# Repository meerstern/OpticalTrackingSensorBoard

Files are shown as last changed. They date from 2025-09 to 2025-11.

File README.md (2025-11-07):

# Optical Tracking Sensor Board

## Feature
  * An optical tracking sensor board using PAT9125EL-TKIT manufactured by PixArt Imaging.  
  * It is possible to detect two-dimensional movement with one sensor.  
  * It can detect object movement at a distance of 1 to 30 mm.
  * No additional lens is required.  
  * Programmable resolution up to 1,275cpi.  
  * It can be easily connected via I2C (Grove compatible connector).  
  * This board is equipped with voltage level conversion, so it can be directly connected to 5V systems such as Arduino Uno.  

## Application
  * Tracking on a Moving Surface  
  * Tracking on the Side of a Rotational Shaft
  
## Note
  * Power/I2C 3.3V-5V  
  * This board is equipped with the PAT9125EL-TKIT, which is an I2C connection type, and does not support SPI connection.

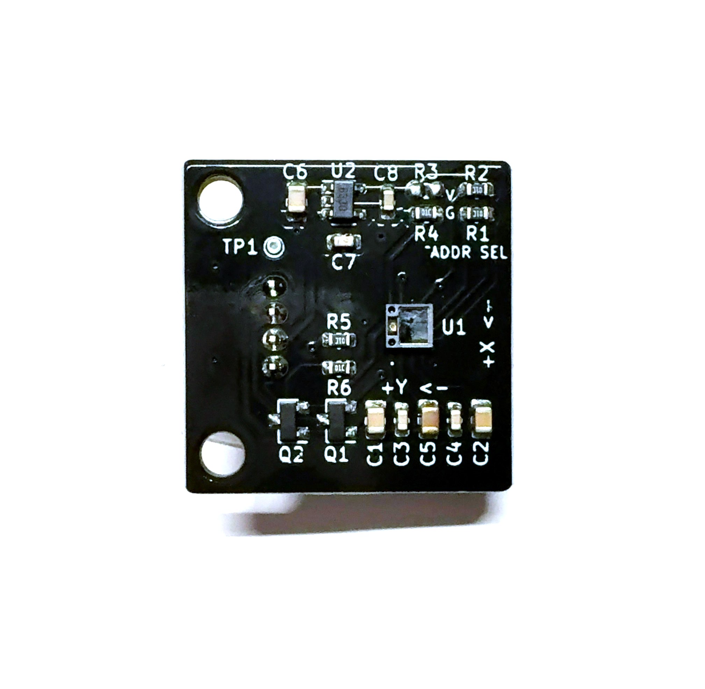
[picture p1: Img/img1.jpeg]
 
   
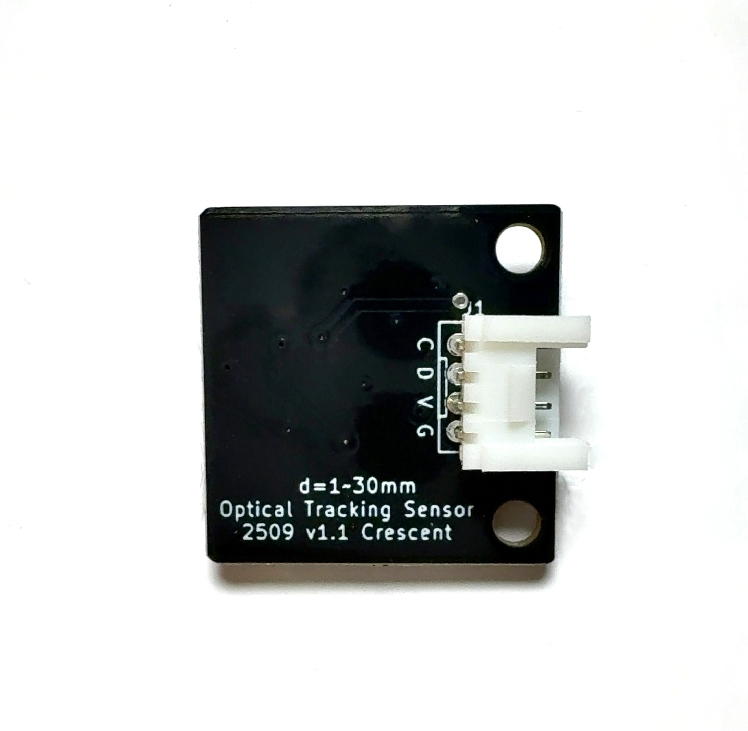
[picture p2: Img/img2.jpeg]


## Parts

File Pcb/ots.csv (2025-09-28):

ID | 参照記号 | パッケージ | 数 | 名称 | Supplier and ref
1 | REF1,REF2 | MountingHole_3.2mm_M3 | 2 | MountingHole_3.2mm_M3
2 | U2 | SOT-23-5 | 1 | LD3985M33R_SOT23
3 | R6,R5,R4,R3,R2,R1 | R_0603_1608Metric | 6 | 10k
4 | Q2,Q1 | SOT-23 | 2 | Q_NMOS_GSD
5 | C8 | C_0603_1608Metric | 1 | 1u
6 | C7 | C_0603_1608Metric | 1 | 10n
7 | C6,C5 | C_0805_2012Metric | 2 | 4.7u
8 | U1 | PAT9125EL | 1 | PAT9125EL
9 | TP1 | TestPoint_THTPad_D1.0mm_Drill0.5mm | 1 | MOTION
10 | J1 | GROVE | 1 | Grove
11 | C4,C3 | C_0603_1608Metric | 2 | 0.1u
12 | C2,C1 | C_0805_2012Metric | 2 | 10u

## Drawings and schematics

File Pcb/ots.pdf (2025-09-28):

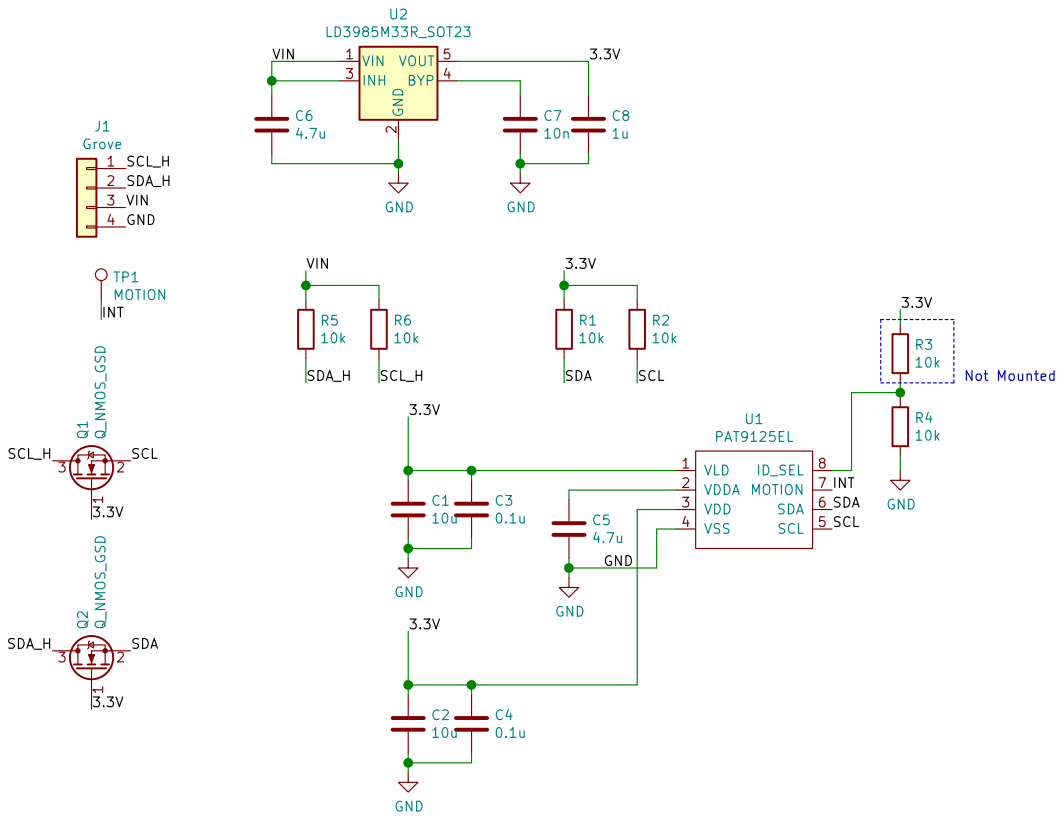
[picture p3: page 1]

Id: 1/1 Title: Optical Tracking Sensor File: ots.sch Sheet: / Crescent

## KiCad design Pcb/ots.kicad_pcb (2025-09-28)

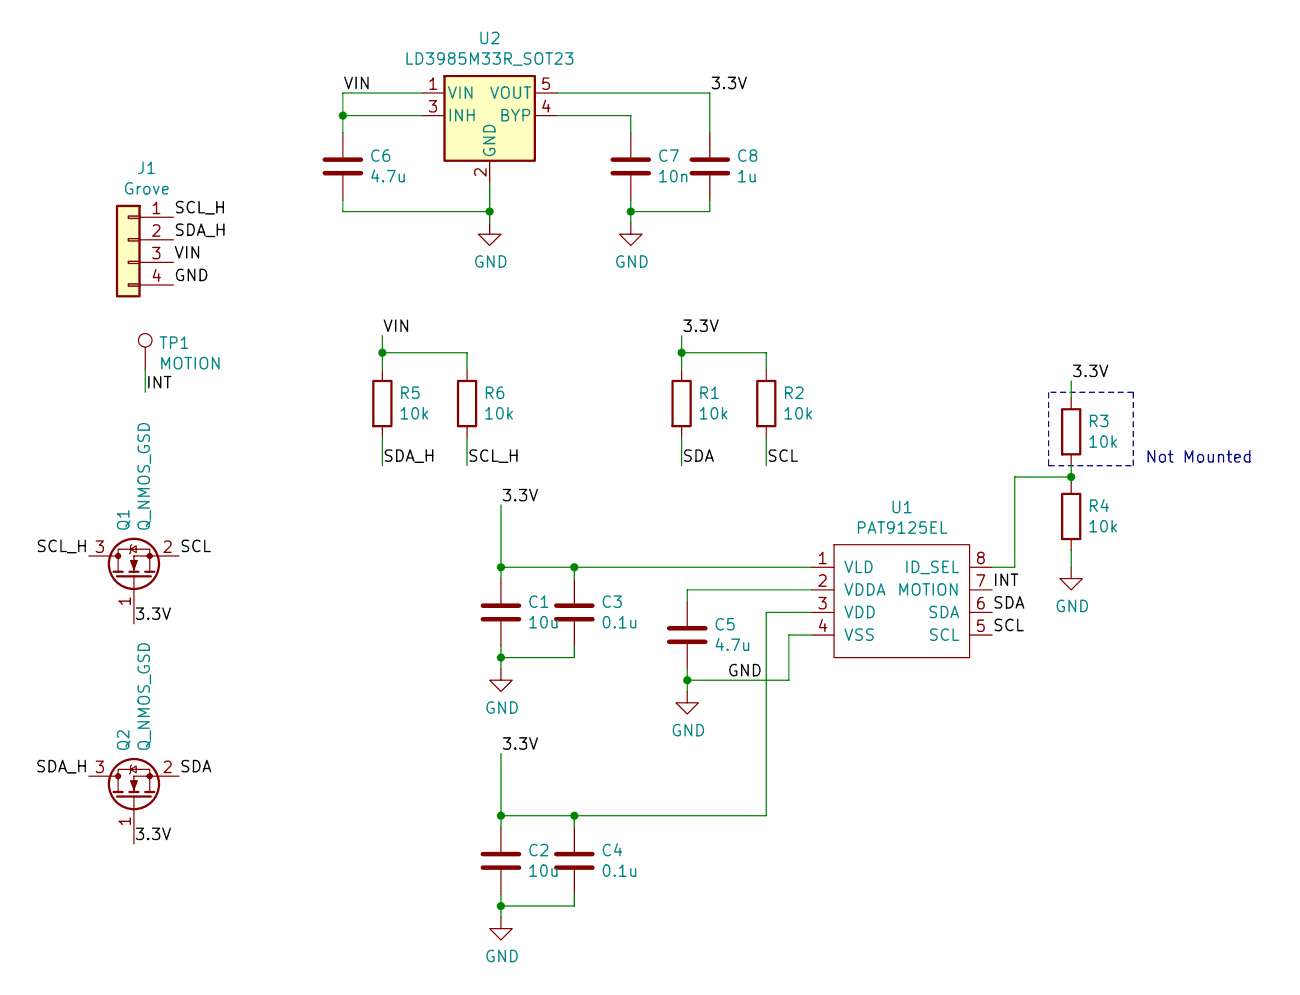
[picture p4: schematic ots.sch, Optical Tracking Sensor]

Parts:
C1, C2: 10u; C_0805_2012Metric
C3, C4: 0.1u; C_0603_1608Metric
C5, C6: 4.7u; C_0805_2012Metric
C7: 10n; C_0603_1608Metric
C8: 1u; C_0603_1608Metric
J1: Grove; GROVE
Q1, Q2: Q_NMOS_GSD; SOT-23
R1, R2, R3, R4, R5, R6: 10k; R_0603_1608Metric
TP1: MOTION; TestPoint_THTPad_D1.0mm_Drill0.5mm
U1: PAT9125EL
U2: LD3985M33R_SOT23; SOT-23-5

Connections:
/3.3V: C1.1, C2.1, C3.1, C4.1, C8.1, Q1.1 (G), Q2.1 (G), R1.1, R2.1, R3.1, U1.1 (VLD), U1.3 (VDD), U2.5 (VOUT)
/INT: TP1.1, U1.7 (MOTION)
/SCL: Q1.2 (S), R2.2, U1.5 (SCL)
/SCL_H: J1.1, Q1.3 (D), R6.2
/SDA: Q2.2 (S), R1.2, U1.6 (SDA)
/SDA_H: J1.2, Q2.3 (D), R5.2
/VIN: C6.1, J1.3, R5.1, R6.1, U2.1 (VIN), U2.3 (INH)
GND: C1.2, C2.2, C3.2, C4.2, C5.2, C6.2, C7.2, C8.2, J1.4, R4.2, U1.4 (VSS), U2.2 (GND)
unnamed: C5.1, U1.2 (VDDA)
unnamed: C7.1, U2.4 (BYP)
unnamed: R3.2, R4.1, U1.8 (ID_SEL)

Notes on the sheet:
Not Mounted

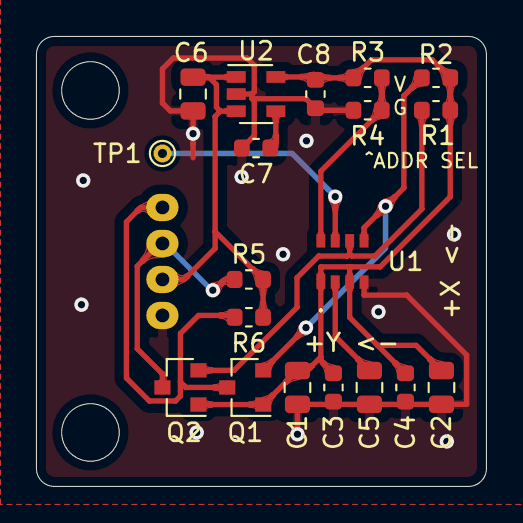
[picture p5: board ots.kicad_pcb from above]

Board: 2 copper layers, 25.0 x 25.0 mm, 22 parts (1 on the bottom side), 11 nets.

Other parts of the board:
REF1, REF2: MountingHole_3.2mm_M3

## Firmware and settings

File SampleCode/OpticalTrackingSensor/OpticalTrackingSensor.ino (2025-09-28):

// PAT9125EL: Miniature Optical Navigation Chip reference code.
// Version: 1.2
// Latest Revision Date: 23 July 2018
// By PixArt Imaging Inc.
// Primary Engineer: Vincent Yeh (PixArt USA)

// Copyright [2018] [Vincent Yeh]
// Licensed under the Apache License, Version 2.0 (the "License"); you may not use this file except in compliance with the License. You may obtain a copy of the License at:
// http://www.apache.org/licenses/LICENSE-2.0

#include <Arduino.h>
#include <Wire.h>

#define WIRE Wire

const uint8_t initialize[][2] = {
    { 0x09, 0x5A },     //Disables write-protect.
    { 0x0D, 0xB5 },     //Sets X-axis resolution (necessary value here will depend on physical design and application).
    { 0x0E, 0xFF },     //Sets Y-axis resolution (necessary value here will depend on physical design and application).
    { 0x19, 0x04 },     //Sets 12-bit X/Y data format.
    //{ 0x4B, 0x04 },     //Needed for when using low-voltage rail (1.7-1.9V): Power saving configuration.
};
#define initialize_size (sizeof(initialize)/sizeof(initialize[0]))

#define I2C_Slave_ID 0x75                           //ONLY WHEN ID PIN IS TIED TO GROUND! ID changes when tied to VDD (0x73) or when left floating (0x79).

int8_t deltaX_low, deltaY_low;                      //Stores the low-bits of movement data.
int16_t deltaX_high, deltaY_high;                   //Stores the high-bits of movement data.
int16_t deltaX, deltaY;                             //Stores the combined value of low and high bits.
int16_t totalX, totalY = 0;                         //Stores the total deltaX and deltaY moved during runtime.

uint8_t readRegister(uint8_t addr)
{
    uint8_t data;
    WIRE.beginTransmission(I2C_Slave_ID);
    WIRE.write(addr);
    WIRE.endTransmission(0);
    WIRE.requestFrom((uint8_t)I2C_Slave_ID,(uint8_t)1);
    data = WIRE.read();
    return(data);
}

void writeRegister(uint8_t addr, uint8_t data)
{
    WIRE.beginTransmission(I2C_Slave_ID);
    WIRE.write(addr);
    WIRE.write(data);
}

void load(const uint8_t array[][2], uint8_t arraySize)
{
    for(uint8_t q = 0; q < arraySize; q++)
    {
        writeRegister(array[q][0], array[q][1]);    //Writes the given array of registers/data.
    }
}

void grabData(void)
{
    deltaX_low = readRegister(0x03);        //Grabs data from the proper registers.
    deltaY_low = readRegister(0x04);
    deltaX_high = (readRegister(0x12)<<4) & 0xF00;      //Grabs data and shifts it to make space to be combined with lower bits.
    deltaY_high = (readRegister(0x12)<<8) & 0xF00;
    
    if(deltaX_high & 0x800)
        deltaX_high |= 0xf000; // 12-bit data convert to 16-bit (two's comp)
        
    if(deltaY_high & 0x800)
        deltaY_high |= 0xf000; // 12-bit data convert to 16-bit (2's comp)
        
    deltaX = deltaX_high | deltaX_low;      //Combined the low and high bits.
    deltaY = deltaY_high | deltaY_low;
}

void printData(void)
{
    if((deltaX != 0) || (deltaY != 0))      //If there is deltaX or deltaY movement, print the data.
    {
        totalX += deltaX;
        totalY += deltaY;
        Serial.print("deltaX: " + String(deltaX) + "\t deltaY:" + String(deltaY)+"\t\t");    //Prints each individual count of deltaX and deltaY.
        Serial.print("X-axis Counts: " + String(totalX) + "\t Y-axis Counts: " + String(totalY) + "\n\r");  //Prints the total movement made during runtime.
    }
    
    deltaX = 0;                             //Resets deltaX and Y values to zero, otherwise previous data is stored until overwritten.
    deltaY = 0;
}

void setup()
{

  Serial.begin(9600);
  WIRE.begin();
  delay(10);
  Serial.println("Optical Tracking Sensor Test Start");

  
  if(readRegister(0x00) != 0x31)
  {
    Serial.println("Communication protocol error! Terminating program.\n\r");
    return 0;
  }
  
  writeRegister(0x06, 0x97);          //Software reset (i.e. set bit7 to 1)
  delay(1);                           //Delay 1 ms for chip reset timing.
  writeRegister(0x06, 0x17);          //Ensure software reset is done and chip is no longer in that state.
  
  load(initialize, initialize_size);  //Load register settings from the "initialize" array
  
  
  
  if(readRegister(0x5E) == 0x04)      //These unlisted registers are used for internal recommended settings.
  {
      writeRegister(0x5E, 0x08);
      
      if(readRegister(0x5D) == 0x10)
          writeRegister(0x5D, 0x19);
  }
  
  writeRegister(0x09, 0x00);  // enable write protect.
}



void loop()
{
  if(readRegister(0x02) & 0x80)
  {
      grabData();
      printData();
  }
  delay(100);
  
}
